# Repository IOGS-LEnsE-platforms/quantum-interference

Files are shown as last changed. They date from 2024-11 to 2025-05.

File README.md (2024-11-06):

# quantum-interference

*LEnsE / Institut d'Optique / Dephi Project / 2025*

## References

P. Grangier, G. Roger, and A. Aspect, “Experimental Evidence for a Photon Anticorrelation Effect on a Beam Splitter: A New Light on SinglePhoton Interferences”, Europys. Lett. 1 (1986), 173-179, abbreviated GRA
in the text.

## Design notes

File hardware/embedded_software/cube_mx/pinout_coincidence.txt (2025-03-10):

Period
======

FCLK = 170 MHz
ARR = 2^16
PSC = 2615

Tout = (ARR + 1)(PSC + 1) / FCLK

Pinout
======

PB_4 -> Out : TIM16 pulse

Interrupts EXTI
---------------
PA_1 - A
PA_4 - B
PA_6 - C
PA_8 - AB
PB_5 - AC
PA_12 - BC
PA_9 - ABC

Others inputs/outputs
---------------------
PA_2 - Analog Potentiometer 
PB_7 - SW1 input
PB_0 - LED1 output

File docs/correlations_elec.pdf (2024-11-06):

## Chapter 6: Coincidence Detection Electronics

Experiments in quantum optics utilizing entangled photons rely on the coincident detection of two or more photons. Some experiments of this type use combinations of time-to-amplitude converters (TAC) and single-channel analyzers (SCA) to detect coincident signals from the photodetectors[5, 6, 10]. The TAC/SCA combinations cost several thousand dollars. This chapter describes a fast logic circuit which fulfils the coincidence counting requirements and can be built for under 40. The circuit is designed to receive 25ns TTL signals and detect coincidences in a 25ns window. The output signals are designed to be 250ns TTL pulses. The coincidence window is not adjustable, but a similar circuit with a different coincidence window is easy to design. Additionally, the design of this circuit can be extended to detect pairs of coincidences between more than two inputs.
A circuit was built according to this design and tests showed it had a coincidence window of between 18ns and 30ns. The output signals where clear and should be easy to count, with a digital counting card for example. The following sections document the design, construction, and performance of the coincidence circuit.

### 6.1 Design

The design for this circuit was published in 2002 by Dehlinger and Mitchell[7]. The only changes from their design to the one described here are two capacitors added for power stability[41]. A schematic is shown in Fig. 6.1(a). The circuit consists of two 74ACT74 dual D-type positive edge-triggered flip-flops, or 4 flip-flops total. Input pulses terminate into a 50Ω load as required by the photodetectors.
Chips 1 and 4 simply relay a pulse received on K to Q. The duration of the pulse from Q depends on the time constant of the RC combination between Q and S, which for the resistor and capacitor chosen is 1kΩ · 220pF = 220ns. This pulse duration should be easy to count with a computer data acquisition card.
Chip 3 in the circuit delays the signal at Bin for the time needed to clock and reset, typically 13ns, with a minimum of 6.5ns and maximum of 19.5ns[42]. In the case of coincident input, the signal from Ain sets D on chip 2 to HIGH before the rising pulse from the delayed Bin triggers the circuit. From the truth table (Table 6.1) it is clear that this combination will issue HIGH on Q, the coincidence output. The RC reset on chip 2 determines the length of the coincidence signal as in chips 1 and 4. Coincidence detection can only occur while Ain is HIGH, so the coincidence window for the 25ns input pulses is 25ns.

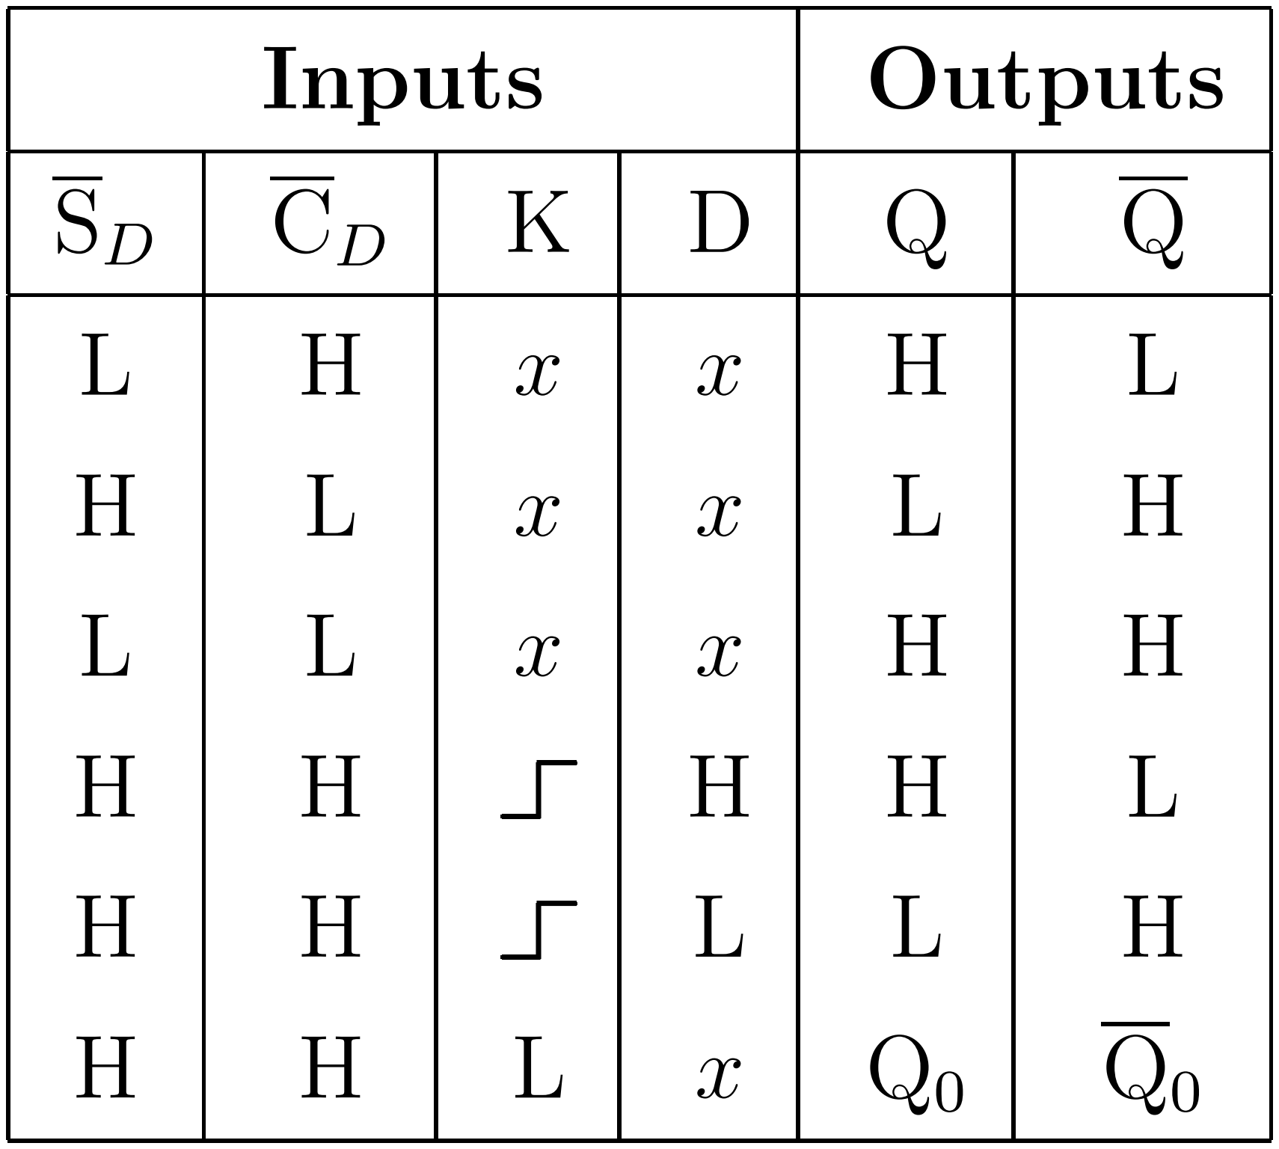
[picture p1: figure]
Inputs; Outputs

Table 6.1: The truth table for each half of a 74ACT74 logic chip. H, L, , and x correspond to TTL HIGH, LOW, rising, and immaterial voltages, respectively[42].

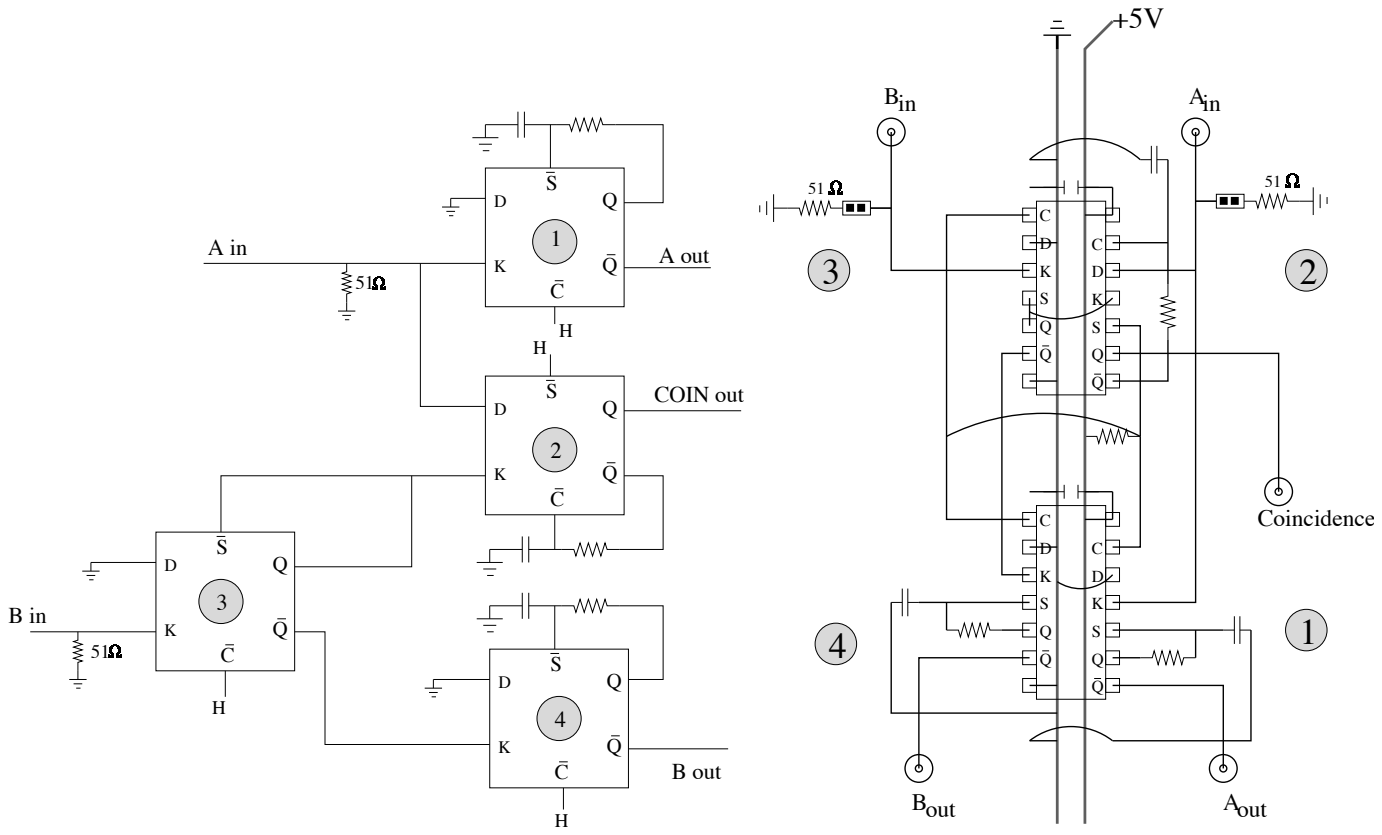
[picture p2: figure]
B out; A out; COIN out; Bin; Ain; Bout; Aout; Coincidence

(a) A schematic diagram of the coincidence detection circuit. Each square is half a 74ACT74 logic chip. H indicates TTL high, +5V .
(b) Diagram of the circuit layout as constructed, including jumpers and additional capacitors across the bus.

Figure 6.1: Two schematic diagrams of the coincidence detection circuit. All capacitors are 220pF except the two across the bus. All resistors are 1kΩ except the two labeled 51Ω.

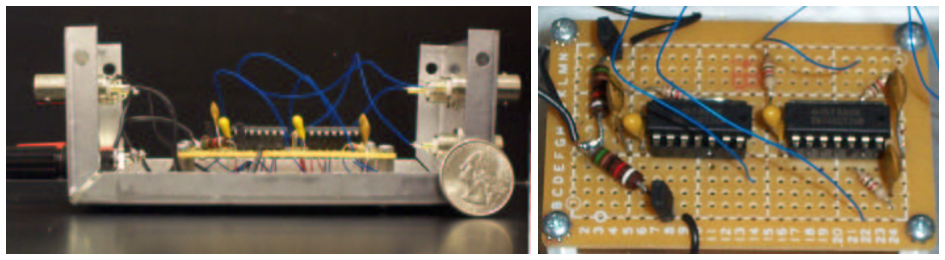
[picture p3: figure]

(a) Side view. | (b) Close up.

Figure 6.2: Pictures of the coincidence circuit.

### 6.2 Construction

The layout of the circuit is shown in Fig. 6.1(b) as assembled on a perforated circuit board with components on top and solder and wiring underneath. Each hole of the board is surrounded by a copper pad to which solder adheres easily. All components are listed in Table 6.2.
The central bus provides stable power and ground to the whole circuit. It was made by soldering two segments of 22 gauge wire to each pad in adjacent rows. By only stripping the portion of the wire to be soldered the wire on the top side remained covered.
The two 14 pin sockets were placed to straddle the bus, and were soldered at each pad. The sockets allow for easy replacement of the logic chips, should it be necessary. A 22µF capacitor was placed across the bus next to the power pin of each chip to increase power stability. A 1kΩ was placed between the bus and the connection point for TTL HIGH for chip protection.
Twenty-two gauge wire was chosen for Ain and Bin, but that choice was unimportant. All remaining wires are 30 gauge because the interconnection soldering is tight and would be difficult to manage with large wire. The wires for the output signals were threaded back up through the board so that any strain is put on the sheathed portion of the wire instead of the connections.
The 51Ω terminations on the inputs are the necessary load required by the photodetectors, but are inhibitory during testing of the circuit. They were joined to the inputs through jumpers so that the terminations can be disconnected by removing the jumper caps.
The completed circuit is mounted inside a metal box to provide electromagnetic shielding and mounts for BNC and banana jacks. The input and output signals travel on BNC cables and the power comes through banana jacks. The connecter holes were drilled with a drill press and drill bit sizes 25

64 and 5
16 for the BNC and
banana jacks, respectively. It was easy to solder wires into the BNC jacks. However, solder did not bond well to the banana jack posts or to the box. In order to avoid the

Item | Qt. | /item
51Ω resistor | 2 | < 1
1kΩ resistor | 4 | < 1
220pF capacitor | 3 | < 1
22µF @16V dc capacitor | 2 | < 1
14-pin socket | 2 | < 1
74ACT74 logic chip | 2 | < 1
Jumper pins | 2 | < 1
Project box | 1 | 3
Perforated circuit board | 1 | 2
Banana jack panel mount | 2 | 1
BNC panel mount | 5 | 1
22 gauge solid wire
30 gauge solid wire
Total < 40

Table 6.2: Materials used to build the coincidence circuit.

need to solder the bus ground to both a banana post and the box, it would be better to use a special grounding banana jack. Fig. 6.2 shows pictures of the completed circuit.
The following are useful notes for anyone attempting to create a similar circuit.

It is difficult to strip 30 gauge wire without a wire stripper.

The stripped portions of any gauge wire are much weaker than the protected portions. The sheath should be kept wherever possible and stripped portions should be bent as little as possible to avoid breaking.

The 30 gauge wire is easier to solder and more robust if it is inserted into the perf board hole than if it is laid sideways on the board.

Some of the connections between pins of the socket and the bus can be made without wire, just by connecting the blobs of solder.

Although some of the components in this circuit were not trimmed short enough to rest on the board, such trimming is a good idea in general since it prevents possible undue strain on the copper pads underneath.

A special grounding banana jack (instead of insulated) is recommended for the ground connection, to remove the need to solder to both the banana post and the box.

### 6.3 Performance

The circuit was tested with a HP 8111A 20MHz function generator and an oscilloscope. The function generator can supply a signal which mimics the 25ns TTL signal from a photodetector we expect as input. The function generator is built for 50Ω signal termination. The oscilloscope was able to display the signals on the circuit inputs and outputs, but ringing made it necessary to use a scope probe, with its shielding connected to the circuit’s ground.
When the signal from the function generator was connected to Ain, Aout showed a 250ns pulse, while Bout and Coinout remained flat. Connecting the signal to Bin produced a 250ns pulse at Bout, while Aout and Coinout remained flat. When the function generator signal was connected to Ain and Bin at the same time it was necessary to disconnect a 50Ω termination by removing a jumper, so that the 50Ω load on the function generated was maintained. In this situation, with signal input at both Ain and Bin, all three outputs showed 250ns pulses.
To make sure that sufficiently separated signals on Ain and Bin are resolved as not coincident, part of the signal from the function generator was subjected to the propagation delay of a 7408 2-input positive AND gate. The propagation delay for that chip is typically 9ns according to the datasheet. When one input received the signal from the function generator and the other input received the signal delayed through 2 AND gates, there was no coincidence detected. However a delay of 1 AND gate was not enough to prevent coincidence detection. This is direct evidence that the circuit has a coincidence window of between 18ns (signal 9ns away on either side are coincident) and 36ns (signal 18ns away on either side are not). This fits our expectation that the window is 25ns, the length of the signal at Ain.

### 6.4 Summary

The circuit described in this chapter detects coincidences for 25ns 50Ω terminated TTL pulses with a coincidence window of 18ns to 36ns. This is ideal for quantum optics experiments which rely on coincident detection of photons using photodetectors such as the SPCM from Perkin-Elmer. The circuit can be constructed easily and for less than 40, and can be tested using a function generator and oscilloscope. As an end note, this circuit can be easily extended to accommodate three or more input signals, as shown in Fig. 6.3. Quantum optics experiments with a gating detector and two signal detectors are common and would use this extended circuit.

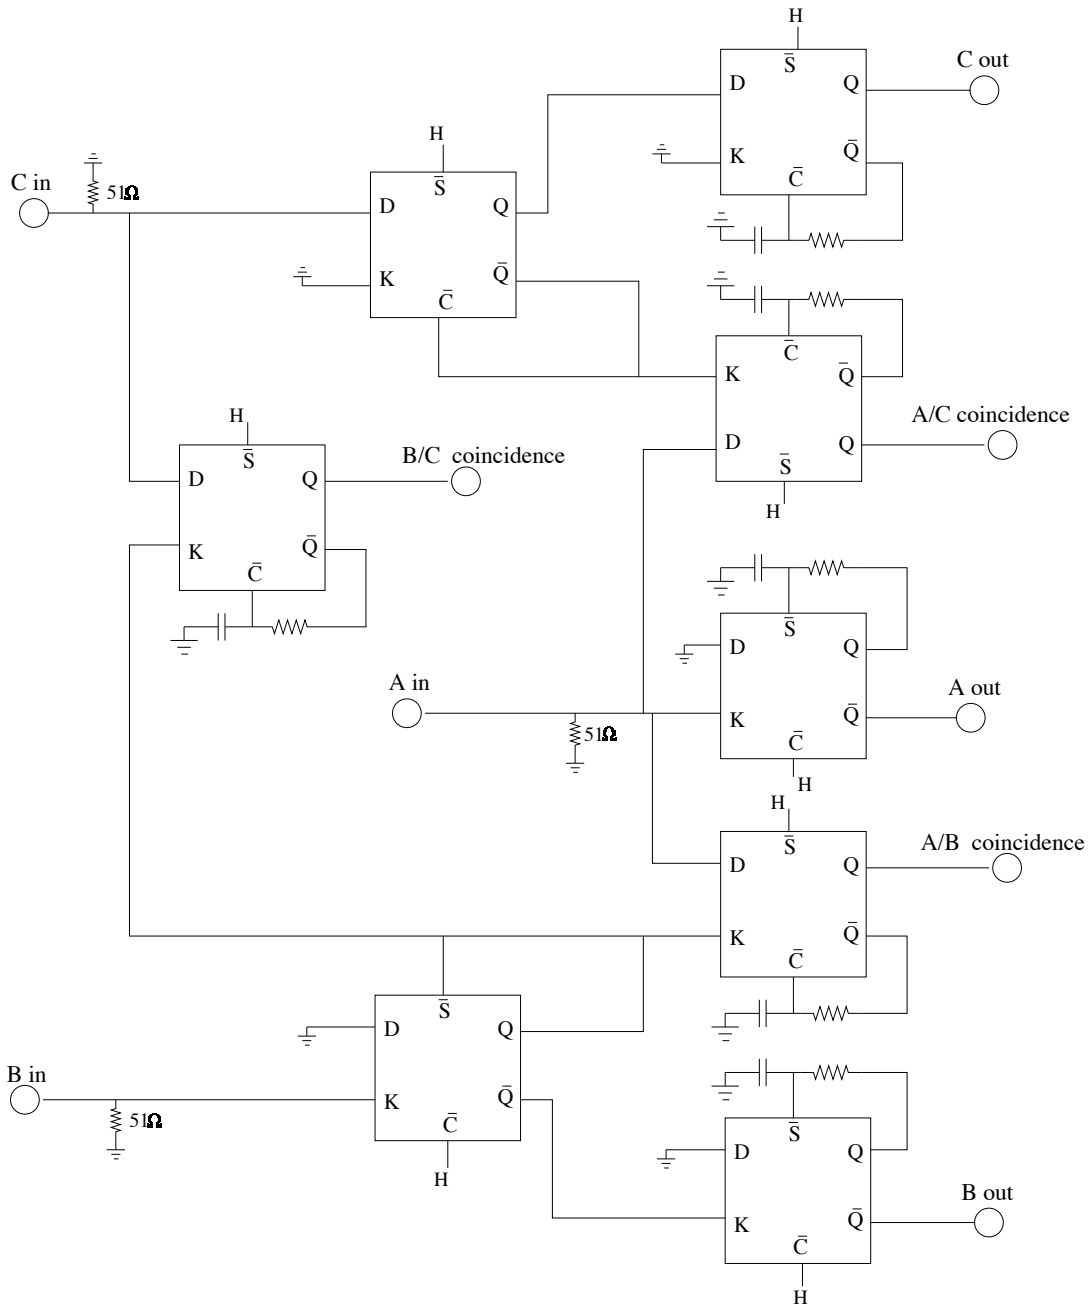
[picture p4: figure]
B/C coincidence; A/B coincidence; B out; A out; A/C coincidence; C out

Figure 6.3: The coincidence circuit extended to detect coincidences between pairs of any three inputs.

### References

[1] A. Einstein, B. Podolsky, and N. Rosen. Can quantum-mechanical description of physical reality be considered complete? Phys. Rev., 47:777–780, 1935.
[2] John S. Bell. On the einstein podalsky rosen paradox. Physics, 1(3):195–200, 1964. This article reprinted in [19].
[3] A. Aspect, P. Grangier, and G. Roger. Experimental tests of realistic local theories via bell’s theorem. Phys. Rev. Lett., 1981.
[4] A. Aspect, P. Grangier, and G. Roger. Experimental realization of einsteinpodalsky-rosen-bohm gedankenexperiment: A new violation of bell’s inequalities. Phys. Rev. Lett., 49:91, 1982.
[5] Paul G. Kwiat, Klaus Mattle, Harald Weinfurter, and Anlon Zeilinger. New high-intensity source of polarization-entangled photon pairs. Physical Review Letters, 75(24):4337–4342, December 1995.
[6] Paul G. Kwiat, Edo Waks, Andrew G. White, Ian Appelbaum, and Philipe H. Eberhard. Ultrabright source of polarization-entangled photons. Physical Review A, 60(2):R773–R776, August 1999.
[7] D. Dehlinger and M. W Mitchell. Entangled photon apparatus for the undergraduate laboratory. Am. J. Phys., 70:898–902, 2002.
[8] D. Dehlinger and M. W Mitchell. Entangled photons, nonlocality, and bell inequalities in the undergraduate laboratory. Am. J. Phys., 70(9):903–910, September 2002.
[9] C. H. Holbrow, E. Galvez, and M. E. Parks. Photon quantum mechanics and beam splitters. Am. J. Phys., 70(3):260–265, March 2002.
[10] J. J. Thorn, M. S. Neel, V. W. Donato, G. S. Bergreen, R. E. Davies, and
M. Beck. Observing the quantum behavior of light in an undergraduate laboratory. Am. J. Phys., 2004. Preprint.
[11] A. K. Ekert. Quantum cryptography based on bell’s theorem. Phys. Rev. Lett., 67:661–663, 1991.
[12] C. H. Bennett. Quantum cryptography using any two nonorthogonal states. Phys. Rev. Lett., 1992.

[13] Gilles | Brassard. | A | bibliography | of | quantum | cryptography.
http://www.cs.mcgill.ca/ crepeau/CRYPTO/Biblio-QC.html, 1998.
[14] Michael A. Neilsen and Isaac L. Chuang. Quantum computation and quantum information. Cambridge U. Press, 2000.
[15] Peter W. Shor. Polynomial-time algorithms for prime factorization and discrete logarithms on a quantum computer. SIAM J. Comput., 26(5):1484–1509, 1997.
[16] David J. Griffiths. Introduction to Quantum Mechanics. Prentice Hall, NJ, 1995.
[17] N David Mermin. Is the moon there when nobody looks? reality and the quantum theory. Physics Today, April 1985.
[18] David Bohm. Quantum Theory. Prentice-Hall, Englewood Cliffs, NJ, 1951. pp. 614-619.
[19] M. Bell, K. Gottfried, and M. Veltman, editors. John S. Bell on The Foundations of Quantun Mechanics. World Scientific, NJ, 2001.
[20] J.F. Clauser, M.A. Horne, A. Shimony, and R.A. Holt. Proposed experiment to test local hidden-variable theories. Phys. Rev. Lett., 23(15):880–884, 1969.
[21] Paul G. Kwiat, Philippe H. Eberhard, Aephraim M. Steinberg, and Raymond Y. Chiao. Proposal for a loophole-free bell inequality experiment. Phys. Rev. A, 49(5):3209–3221, May 1994.
[22] P. H. Eberhard. Phys. Rev. A, 1993.
[23] P. Grangier, G. Roger, and A. Aspect. Experimental evidence for a photon anticorrelation effect on a beam splitter: A new light on single-photon interferences. Europhys. Lett., 1986.
[24] Robert W. Boyd. Nonlinear Optics. Academic Press, second edition, 2003.
[25] Xinping Zhang. High-repitition-rate Femtosecond Optical Parametric Oscillators Based on KTP and PPLN. PhD thesis, Philipps-Universit¨at Marburg, Marburg, Germany, 2002. Chapter 2.
[26] Cleveland Crystals Inc. BBO and LBO. http://www.clevelandcrystals.com/BBOLBO.shtml.
[27] Almaz Optics Inc. BBO crystal. http://www.almazoptics.com/Bbo.htm.
[28] SDLN Coretech Crystal Co. Beta barium borate. http://www.coretech.com.cn/BBO.HTM.

[29] Paul G. Kwiat. J. Mod. Opt., 44:2173, 1997.
[30] R. Y. Chiao, P. G. Kwiat, and A. M. Steinberg. Optical tests of quantum mechanics. In Advances in Atomic, Molecular, and Optical Physics, volume 34, pages 35–83. Academic, 1994.
[31] Photon quantum mechanics. Internet. http://departments.colgate.edu/physics/research/Photon/photon_quantum_m%echanics.htm.
[32] M.K. Beck. Modern quantum mechanics experiments for undergraduates. Internet, 2004. http://marcus.whitman.edu/~beckmk/QM/.
[33] Edmund Optics. Solid state lasers. http://www.edmundoptics.com/, April 2004.
[34] Eugene Hecht. Optics. Pearson Addison Wesley, 4th edition, 2001.
[35] Casix Inc. Waveplates. http://casix.com/product/Waveplate.htm.
[36] Perkin-Elmer Optoelectronics. Single photon counting module, SPCM-AQR series. Internet. Datasheet.
[37] Perkin-Elmer Optoelectronics. SPCM-AQ4C, single photon counting array. Internet. Datasheet.
[38] Perkin-Elmer Optoelectronics. SPCM AQ4C Four Channel Photon Counting Module–User Guide, May 2003.
[39] D.W. Finn and M. J. Ouellette. Compact fluorescent lamps: What you should know. Progressive Architecture, pages 89–92, August 1992.
[40] John R. Taylor. Introduction to Error Analysis. University Science Books, CA, second edition, 1997.
[41] William Mohler. Personal Communication, 2003. Oberlin College.
[42] Semiconductor Components Industries, LLC. 74ACT74 Datasheet, May 2001. <http://onsemi.com>.

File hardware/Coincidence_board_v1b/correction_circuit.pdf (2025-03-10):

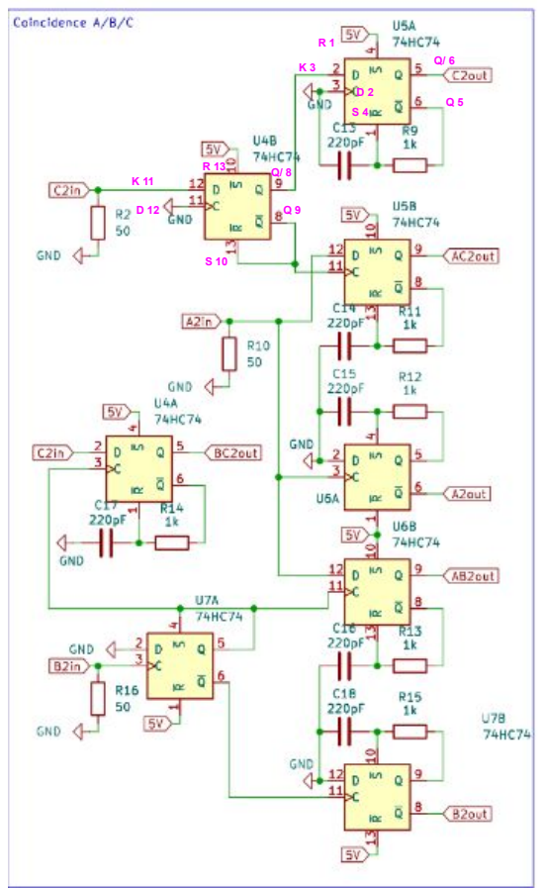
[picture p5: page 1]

R 13 | Q/ 8

Q 9

S 10

K 11

D 12

Q/ 6

Q 5
S 4

D 2

K 3

R 1

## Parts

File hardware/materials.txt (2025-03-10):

Coincidence Board v2
====================
	Developed by LEnsE / 2025

Board with Nucleo G431KB 
D-Flip 74HC74 PDIP circuits

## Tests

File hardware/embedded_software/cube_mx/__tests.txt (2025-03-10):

Test on Nucleo G431KB

// Embedded program //
======================

+ 10/03/2025 - JV - Test coincidence_v1 program (HAL and CubeIDE)
-----------------------------------------------------------------
- Test with 7 inputs (interrupt EXTI) :
	+ pulses of 250 ns, amplitude 0-3V
- Results
	+ A/B/C -> 600 kHz
	+ AB/BC/AC/ABC -> 50 kHz

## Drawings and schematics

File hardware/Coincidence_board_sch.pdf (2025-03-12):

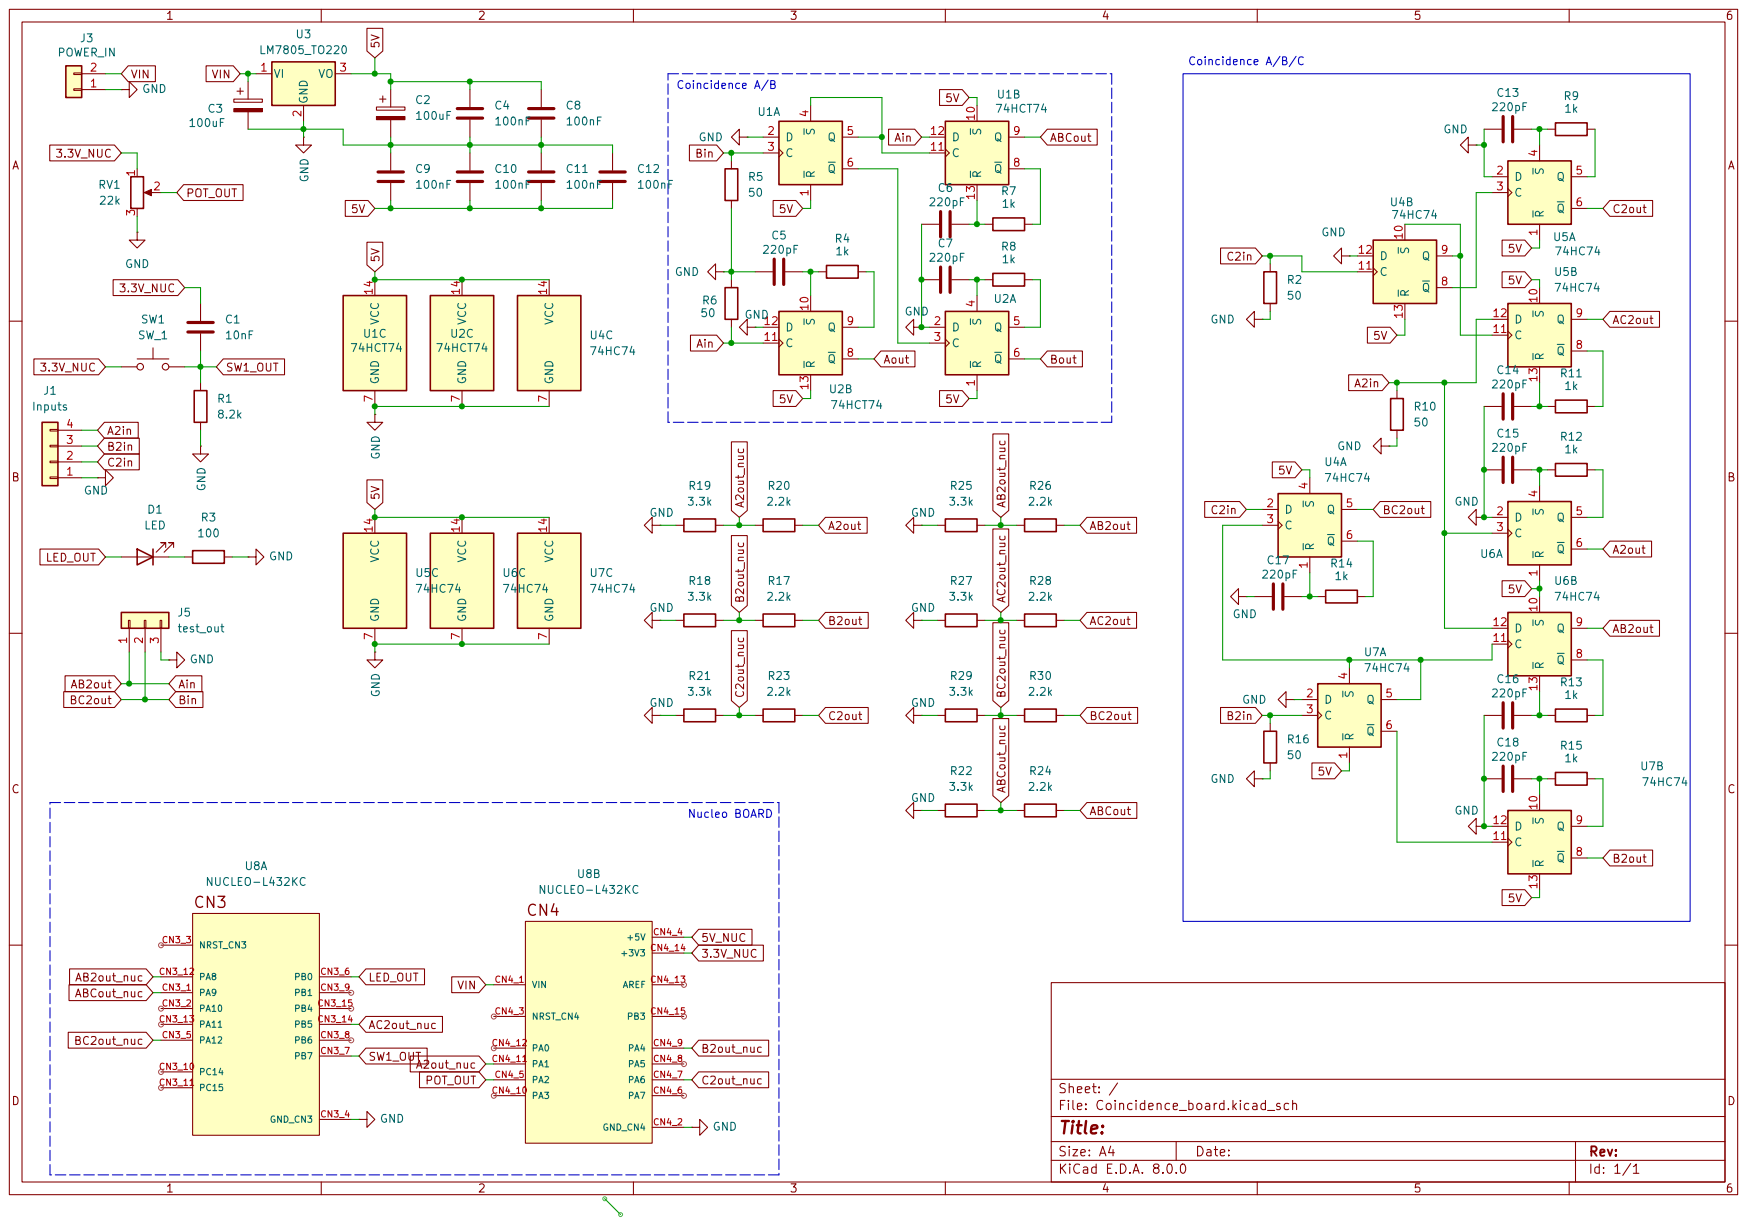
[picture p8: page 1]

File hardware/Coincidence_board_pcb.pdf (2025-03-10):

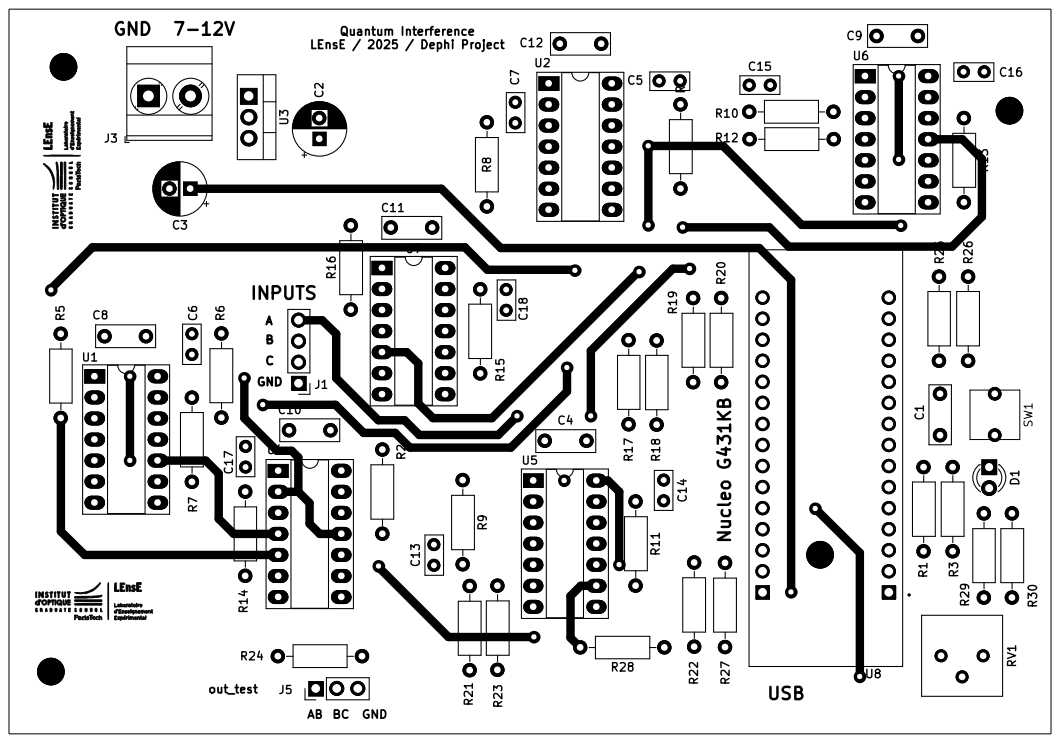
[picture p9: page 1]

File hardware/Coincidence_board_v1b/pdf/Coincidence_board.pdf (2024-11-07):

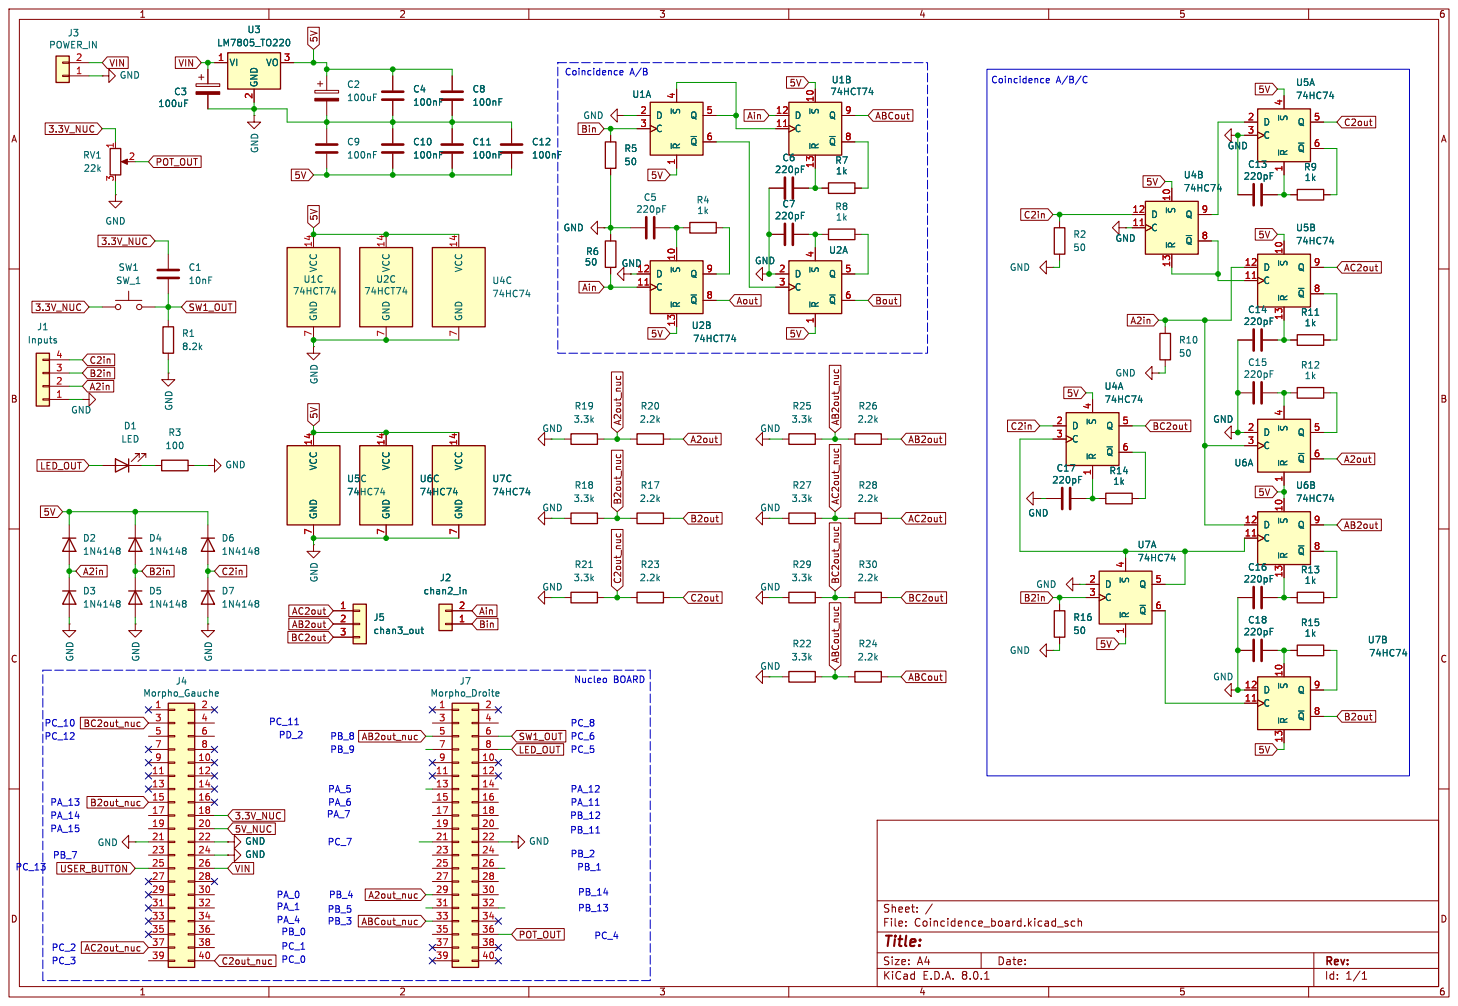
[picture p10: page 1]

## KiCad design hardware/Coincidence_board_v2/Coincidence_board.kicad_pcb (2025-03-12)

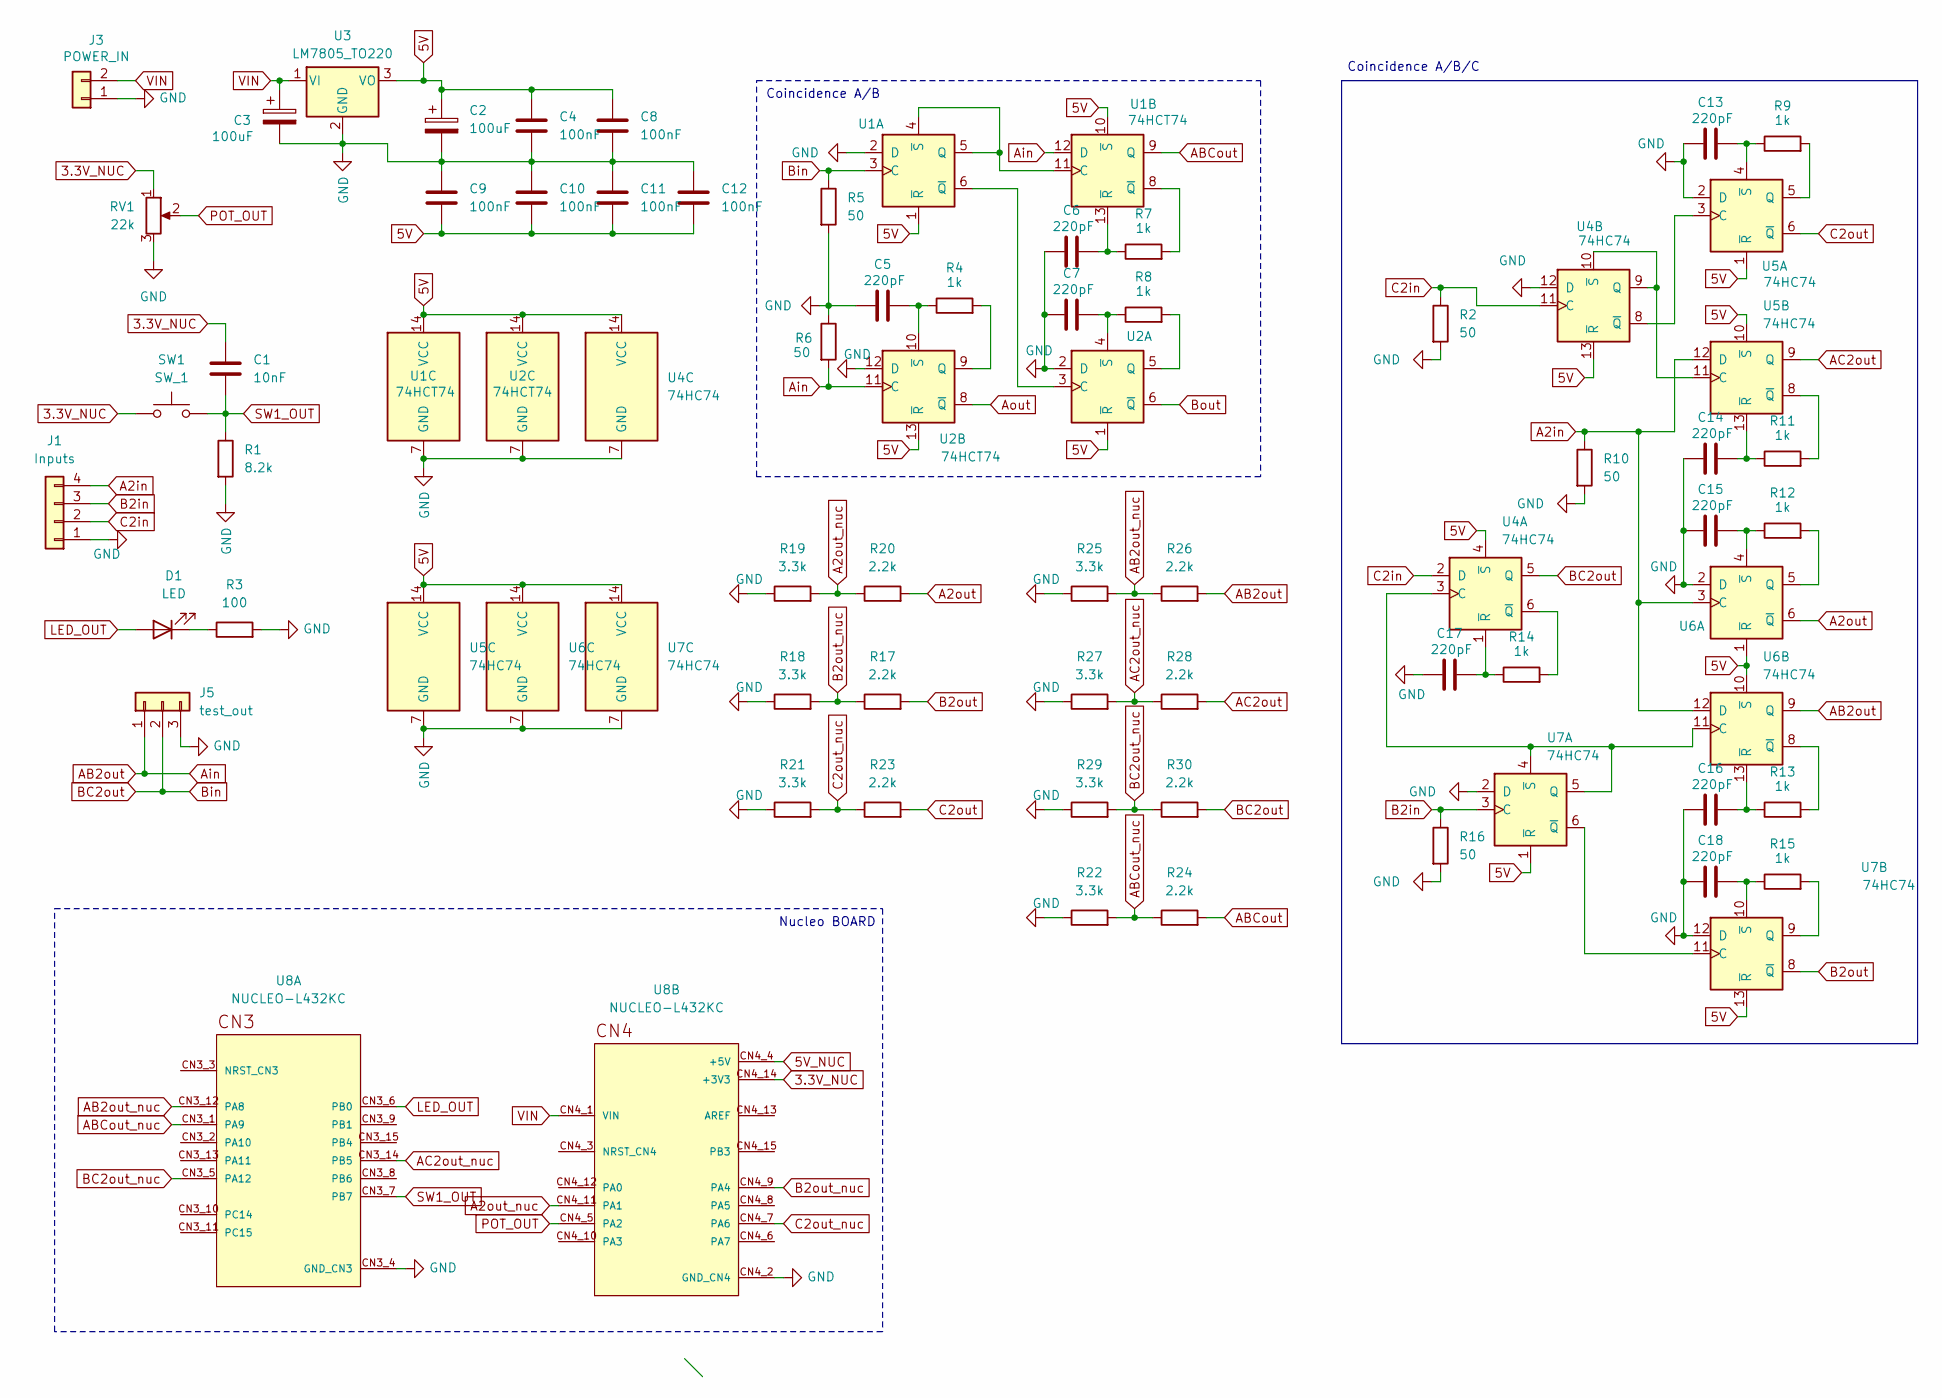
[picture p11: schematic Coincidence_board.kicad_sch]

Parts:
C1: 10nF; C_Rect_L7.0mm_W2.5mm_P5.00mm
C2, C3: 100uF; CP_Radial_D6.3mm_P2.50mm
C4, C8, C9, C10, C11, C12: 100nF; C_Rect_L7.0mm_W2.5mm_P5.00mm
C5, C6, C7, C13, C14, C15, C16, C17, C18: 220pF; C_Rect_L4.6mm_W2.0mm_P2.50mm_MKS02_FKP02
D1: LED; LED_D3.0mm_Clear
J1: Inputs; PinHeader_1x04_P2.54mm_Vertical
J3: POWER_IN; TerminalBlock_Phoenix_MKDS-3-2-5.08_1x02_P5.08mm_Horizontal
J5: test_out; PinHeader_1x03_P2.54mm_Vertical
R1: 8.2k; R_Axial_DIN0207_L6.3mm_D2.5mm_P10.16mm_Horizontal
R2, R5, R6, R10, R16: 50; R_Axial_DIN0207_L6.3mm_D2.5mm_P10.16mm_Horizontal
R3: 100; R_Axial_DIN0207_L6.3mm_D2.5mm_P10.16mm_Horizontal
R4, R7, R8, R9, R11, R12, R13, R14, R15: 1k; R_Axial_DIN0207_L6.3mm_D2.5mm_P10.16mm_Horizontal
R17, R20, R23, R24, R26, R28, R30: 2.2k; R_Axial_DIN0207_L6.3mm_D2.5mm_P10.16mm_Horizontal
R18, R19, R21, R22, R25, R27, R29: 3.3k; R_Axial_DIN0207_L6.3mm_D2.5mm_P10.16mm_Horizontal
RV1: 22k; Potentiometer_Bourns_3386P_Vertical
SW1: SW_1; Switch
U1, U2: 74HCT74; DIP-14_W7.62mm_Socket_LongPads
U3: LM7805_TO220; TO-220-3_Vertical
U4, U5, U6, U7: 74HC74; DIP-14_W7.62mm_Socket_LongPads
U8: NUCLEO-L432KC; MODULE_NUCLEO-L432KC; PARTREV N/A

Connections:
3.3V_NUC: C1.1, RV1.1, SW1.1, U8.CN4_14 (+3V3)
5V: C2.1, C4.1, C8.1, C9.2, C10.2, C11.2, C12.2, U1.1 (~R), U1.10 (~S), U1.14 (VCC), U2.1 (~R), U2.13 (~R), U2.14 (VCC), U3.3 (VO), U4.4 (~S), U4.13 (~R), U4.14 (VCC), U5.1 (~R), U5.10 (~S), U5.14 (VCC), U6.1 (~R), U6.10 (~S), U6.14 (VCC), U7.1 (~R), U7.13 (~R), U7.14 (VCC)
5V_NUC: U8.CN4_4 (+5V)
A2in: J1.4, R10.1, U5.12 (D), U6.3 (C), U6.12 (D)
A2out: R20.2, U6.6 (~Q)
A2out_nuc: R19.2, R20.1, U8.CN4_11 (PA1)
AB2out: J5.1, R6.2, R26.2, U1.12 (D), U2.11 (C), U6.9 (Q)
AB2out_nuc: R25.2, R26.1, U8.CN3_12 (PA8)
ABCout: R24.2, U1.9 (Q)
ABCout_nuc: R22.2, R24.1, U8.CN3_1 (PA9)
AC2out: R28.2, U5.9 (Q)
AC2out_nuc: R27.2, R28.1, U8.CN3_14 (PB5)
Aout: U2.8 (~Q)
B2in: J1.3, R16.1, U7.3 (C)
B2out: R17.2, U7.8 (~Q)
B2out_nuc: R17.1, R18.2, U8.CN4_9 (PA4)
BC2out: J5.2, R5.1, R30.2, U1.3 (C), U4.5 (Q)
BC2out_nuc: R29.2, R30.1, U8.CN3_5 (PA12)
Bout: U2.6 (~Q)
C2in: J1.2, R2.1, U4.2 (D), U4.11 (C)
C2out: R23.2, U5.6 (~Q)
C2out_nuc: R21.2, R23.1, U8.CN4_7 (PA6)
GND: C2.2, C3.2, C4.2, C5.1, C6.1, C7.1, C8.2, C9.1, C10.1, C11.1, C12.1, C13.1, C14.1, C15.1, C16.1, C17.1, C18.1, J1.1, J3.1, J5.3, R1.2, R2.2, R3.2, R5.2, R6.1, R10.2, R16.2, R18.1, R19.1, R21.1, R22.1, R25.1, R27.1, R29.1, RV1.3, U1.2 (D), U1.7 (GND), U2.2 (D), U2.7 (GND), U2.12 (D), U3.2 (GND), U4.7 (GND), U4.12 (D), U5.2 (D), U5.7 (GND), U6.2 (D), U6.7 (GND), U7.2 (D), U7.7 (GND), U7.12 (D), U8.CN3_4 (GND_CN3), U8.CN4_2 (GND_CN4)
LED_OUT: D1.2 (A), U8.CN3_6 (PB0)
unnamed: D1.1 (K), R3.1
unnamed: U1.4 (~S), U1.5 (Q), U1.11 (C)
unnamed: U1.6 (~Q), U2.3 (C)
unnamed: R7.2, U1.8 (~Q)
unnamed: C6.2, R7.1, U1.13 (~R)
unnamed: R8.2, U2.5 (Q)
unnamed: C7.2, R8.1, U2.4 (~S)
unnamed: R4.2, U2.9 (Q)
unnamed: C5.2, R4.1, U2.10 (~S)
unnamed: U4.3 (C), U6.11 (C), U7.4 (~S), U7.5 (Q)
unnamed: R14.2, U4.6 (~Q)
unnamed: C17.2, R14.1, U4.1 (~R)
unnamed: U4.9 (Q), U4.10 (~S), U5.11 (C)
unnamed: U4.8 (~Q), U5.3 (C)
unnamed: R9.2, U5.5 (Q)
unnamed: C13.2, R9.1, U5.4 (~S)
unnamed: R11.2, U5.8 (~Q)
unnamed: C14.2, R11.1, U5.13 (~R)
unnamed: R12.2, U6.5 (Q)
unnamed: C15.2, R12.1, U6.4 (~S)
unnamed: R13.2, U6.8 (~Q)
unnamed: C16.2, R13.1, U6.13 (~R)
unnamed: U7.6 (~Q), U7.11 (C)
unnamed: R15.2, U7.9 (Q)
unnamed: C18.2, R15.1, U7.10 (~S)
POT_OUT: RV1.2, U8.CN4_5 (PA2)
SW1_OUT: C1.2, R1.1, SW1.2, U8.CN3_7 (PB7)
VIN: C3.1, J3.2, U3.1 (VI), U8.CN4_1 (VIN)

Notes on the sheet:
Coincidence A/B
Coincidence A/B/C
Nucleo BOARD

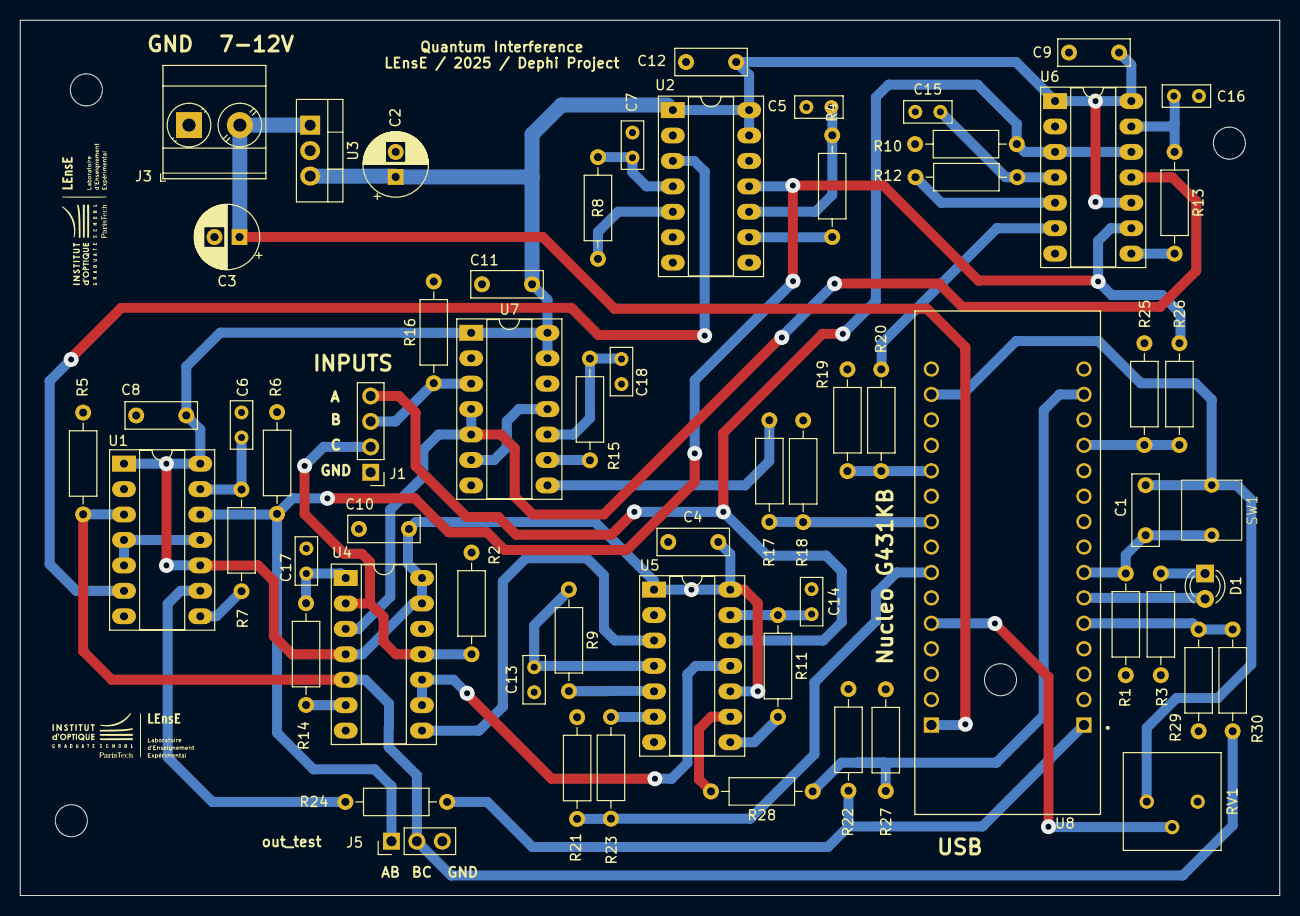
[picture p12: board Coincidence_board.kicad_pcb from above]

Board: 2 copper layers, 125.8 x 87.4 mm, 64 parts (0 on the bottom side), 49 nets.

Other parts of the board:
M: MountingHole_3.2mm_M3
M#2: MountingHole_3.2mm_M3

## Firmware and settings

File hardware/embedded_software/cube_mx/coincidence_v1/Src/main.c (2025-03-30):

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
/* Includes ------------------------------------------------------------------*/
#include "main.h"
#include "lptim.h"
#include "tim.h"
#include "usart.h"
#include "gpio.h"

/* USER CODE BEGIN Includes */
#include <stdbool.h>
#include <stdio.h>
#include <string.h>

/* USER CODE END Includes */


/* USER CODE BEGIN PV */
char 		txBuffer[20] = {0};
int			a_counter = 0, a_counter_save = 0;
int			b_counter = 0, b_counter_save = 0;
int			c_counter = 0, c_counter_save = 0;
int			ab_counter = 0, ab_counter_save = 0;
int			ac_counter = 0, ac_counter_save = 0;
int			bc_counter = 0, bc_counter_save = 0;
int			abc_counter = 0, abc_counter_save = 0;

/*Configure GPIO pins : PA4 PA5 PA6 PA7
                         PA8 PA9 PA10 PA11 */


/* USER CODE END PV */

void SystemClock_Config(void);
/**
  * @brief  The application entry point.
  * @retval int
  */
int main(void)
{

  /* MCU Configuration--------------------------------------------------------*/

  /* Reset of all peripherals, Initializes the Flash interface and the Systick. */
  HAL_Init();

  /* Configure the system clock */
  SystemClock_Config();

  /* Initialize all configured peripherals */
  MX_GPIO_Init();
  MX_USART2_UART_Init();
  MX_LPTIM1_Init();
  MX_TIM16_Init();
  /* USER CODE BEGIN 2 */
  // TIM16 - 16 bits Timer / Period = (PSC+1)(ARR+1) / 170MHz  (??)  ARR = 2^16
  // For PSC = 2615 -> T = 1000ms

  // Init
  txBuffer[0] = 'Z';
  txBuffer[1] = '\r';
  txBuffer[2] = '\n';
  txBuffer[3] = '\0';


  // Start TIM16 timer
  HAL_TIM_Base_Start_IT(&htim16);
  /* USER CODE END 2 */

  /* Infinite loop */
  /* USER CODE BEGIN WHILE */
  while (1)
  {
	//HAL_UART_Transmit(&huart2, txBuffer, 4, 1000);
	//HAL_Delay(100);

    /* USER CODE END WHILE */

    /* USER CODE BEGIN 3 */
  }
  /* USER CODE END 3 */
}

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
/* USER CODE BEGIN 4 */
// Interrupt on EXTI - PA4, PA5...
void HAL_GPIO_EXTI_Callback(uint16_t GPIO_Pin)
{
    if(GPIO_Pin == GPIO_PIN_1) // If The INT Source Is EXTI Line1 (A1 Pin)
    {
    	a_counter++;
    }
    if(GPIO_Pin == GPIO_PIN_4) // If The INT Source Is EXTI Line4 (A4 Pin)
    {
    	b_counter++;
    }
    if(GPIO_Pin == GPIO_PIN_6) // If The INT Source Is EXTI Line6 (A6 Pin)
    {
    	c_counter++;
    }
    if(GPIO_Pin == GPIO_PIN_8) // If The INT Source Is EXTI Line8 (A8 Pin)
    {
    	ab_counter++;
    }
    if(GPIO_Pin == GPIO_PIN_9) // If The INT Source Is EXTI Line9 (A9 Pin)
    {
    	abc_counter++;
    }
    if(GPIO_Pin == GPIO_PIN_12) // If The INT Source Is EXTI Line12 (A12 Pin)
    {
    	bc_counter++;
    }
    if(GPIO_Pin == GPIO_PIN_5) // If The INT Source Is EXTI Line5 (PB5 Pin)
    {
    	ac_counter++;
    }
}

// Interrupt on TIM - TIM16
void HAL_TIM_PeriodElapsedCallback(TIM_HandleTypeDef* htim)
{
    HAL_GPIO_WritePin(GPIOB, GPIO_PIN_4, GPIO_PIN_SET);
    a_counter_save = a_counter;
    a_counter = 0;
    b_counter_save = b_counter;
    b_counter = 0;
    c_counter_save = c_counter;
    c_counter = 0;
    ab_counter_save = ab_counter;
    ab_counter = 0;
    ac_counter_save = ac_counter;
    ac_counter = 0;
    bc_counter_save = bc_counter;
    bc_counter = 0;
    abc_counter_save = abc_counter;
    abc_counter = 0;
	sprintf(txBuffer, "A=%d\n", a_counter_save+1);
    HAL_UART_Transmit(&huart2, (uint8_t *)txBuffer, strlen(txBuffer), 1000);
	sprintf(txBuffer, "B=%d\n", b_counter_save+1);
    HAL_UART_Transmit(&huart2, (uint8_t *)txBuffer, strlen(txBuffer), 1000);
	sprintf(txBuffer, "C=%d\n", c_counter_save+1);
    HAL_UART_Transmit(&huart2, (uint8_t *)txBuffer, strlen(txBuffer), 1000);
	sprintf(txBuffer, "AB=%d\n", ab_counter_save+1);
    HAL_UART_Transmit(&huart2, (uint8_t *)txBuffer, strlen(txBuffer), 1000);
	sprintf(txBuffer, "AC=%d\n", ac_counter_save+1);
    HAL_UART_Transmit(&huart2, (uint8_t *)txBuffer, strlen(txBuffer), 1000);
	sprintf(txBuffer, "BC=%d\n", bc_counter_save+1);
    HAL_UART_Transmit(&huart2, (uint8_t *)txBuffer, strlen(txBuffer), 1000);
	sprintf(txBuffer, "ABC=%d\n", abc_counter_save+1);
    HAL_UART_Transmit(&huart2, (uint8_t *)txBuffer, strlen(txBuffer), 1000);
    HAL_GPIO_WritePin(GPIOB, GPIO_PIN_4, GPIO_PIN_RESET);
}
/* USER CODE END 4 */
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


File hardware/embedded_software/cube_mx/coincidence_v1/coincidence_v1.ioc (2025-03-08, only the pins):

Mcu.UserName=STM32G431KBTx
PA1.Signal=GPXTI1
PA12.Signal=GPXTI12
PA13.GPIO_Label=T_SWDIO
PA13.Signal=SYS_JTMS-SWDIO
PA14.GPIO_Label=T_SWCLK
PA14.Signal=SYS_JTCK-SWCLK
PA2.GPIO_Label=USART2_TX [ST-LINKV3E_VCP_RX]
PA2.Signal=USART2_TX
PA3.GPIO_Label=USART2_RX [ST-LINKV3E_VCP_TX]
PA3.Signal=USART2_RX
PA4.Signal=GPXTI4
PA6.Signal=GPXTI6
PA8.Signal=GPXTI8
PA9.Signal=GPXTI9
PB3.GPIO_Label=T_SWO
PB3.Signal=SYS_JTDO-SWO
PB4.Signal=GPIO_Output
PB5.Signal=GPXTI5
PB8-BOOT0.GPIO_Label=LD2 [green]
PB8-BOOT0.Signal=GPIO_Output

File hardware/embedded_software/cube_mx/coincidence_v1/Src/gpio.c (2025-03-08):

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

/* Includes ------------------------------------------------------------------*/
#include "gpio.h"

/*----------------------------------------------------------------------------*/
/* Configure GPIO                                                             */
/*----------------------------------------------------------------------------*/
/** Configure pins as
        * Analog
        * Input
        * Output
        * EVENT_OUT
        * EXTI
*/
void MX_GPIO_Init(void)
{

  GPIO_InitTypeDef GPIO_InitStruct = {0};

  /* GPIO Ports Clock Enable */
  __HAL_RCC_GPIOA_CLK_ENABLE();
  __HAL_RCC_GPIOB_CLK_ENABLE();

  /*Configure GPIO pin Output Level */
  HAL_GPIO_WritePin(GPIOB, GPIO_PIN_4|LD2_Pin, GPIO_PIN_RESET);

  /*Configure GPIO pins : PA1 PA4 PA6 PA8
                           PA9 PA12 */
  GPIO_InitStruct.Pin = GPIO_PIN_1|GPIO_PIN_4|GPIO_PIN_6|GPIO_PIN_8
                          |GPIO_PIN_9|GPIO_PIN_12;
  GPIO_InitStruct.Mode = GPIO_MODE_IT_RISING;
  GPIO_InitStruct.Pull = GPIO_NOPULL;
  HAL_GPIO_Init(GPIOA, &GPIO_InitStruct);

  /*Configure GPIO pins : PB4 LD2_Pin */
  GPIO_InitStruct.Pin = GPIO_PIN_4|LD2_Pin;
  GPIO_InitStruct.Mode = GPIO_MODE_OUTPUT_PP;
  GPIO_InitStruct.Pull = GPIO_NOPULL;
  GPIO_InitStruct.Speed = GPIO_SPEED_FREQ_LOW;
  HAL_GPIO_Init(GPIOB, &GPIO_InitStruct);

  /*Configure GPIO pin : PB5 */
  GPIO_InitStruct.Pin = GPIO_PIN_5;
  GPIO_InitStruct.Mode = GPIO_MODE_IT_RISING;
  GPIO_InitStruct.Pull = GPIO_NOPULL;
  HAL_GPIO_Init(GPIOB, &GPIO_InitStruct);

  /* EXTI interrupt init*/
  HAL_NVIC_SetPriority(EXTI1_IRQn, 0, 0);
  HAL_NVIC_EnableIRQ(EXTI1_IRQn);

  HAL_NVIC_SetPriority(EXTI4_IRQn, 0, 0);
  HAL_NVIC_EnableIRQ(EXTI4_IRQn);

  HAL_NVIC_SetPriority(EXTI9_5_IRQn, 0, 0);
  HAL_NVIC_EnableIRQ(EXTI9_5_IRQn);

  HAL_NVIC_SetPriority(EXTI15_10_IRQn, 0, 0);
  HAL_NVIC_EnableIRQ(EXTI15_10_IRQn);

}



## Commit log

2024-11-06 Update Files / Adding Arduino Code for Nucleo board for rate testing
    [Coincidence_board.kicad_pcb, Coincidence_board.kicad_sch]
2024-11-06 Update Coincidence Board / Dephi 2024
    [Coincidence_board-B_Cu.gbr, Coincidence_board-B_Mask.gbr, Coincidence_board-B_Paste.gbr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]
2024-11-07 Update Schematics of Electronic Board
    [Coincidence_board-B_Cu.gbr, Coincidence_board-B_Mask.gbr, Coincidence_board-B_Paste.gbr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]
2024-11-07 Update Test on Nucleo Board - up to 80kHz !!
2024-11-08 Update Schematic
    [Coincidence_board-B_Cu.gbr, Coincidence_board-B_Mask.gbr, Coincidence_board-B_Paste.gbr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]
2025-03-06 Update Coincidence Board / New schematics (Anouk - Jeanne)
    Test with Nucleo L476RG ? Not fast enough ??
    [Coincidence_board-B_Cu.gbr, Coincidence_board-B_Mask.gbr, Coincidence_board-B_Paste.gbr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]
2025-03-06 Update Coincidence Board / 2025 version
    [Coincidence_board-B_Cu.gbr, Coincidence_board-B_Mask.gbr, Coincidence_board-B_Paste.gbr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]
2025-03-07 Create CubeIDE project for STM32 Nucleo board / G431KB
2025-03-08 Update MXIDE code / Adding USART2 transmission of characters / Tested on G431KB and TeraTerm
    [Coincidence_board-B_Cu.gbr, Coincidence_board-B_Mask.gbr, Coincidence_board-B_Paste.gbr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]
2025-03-08 Update Embedded program / STM32CubeIDE / HAL version with 7 EXTI !
    Need to test on 7 inputs / Max frequency ?
2025-03-10 Update Quantum
    [Coincidence_board.kicad_pcb, Coincidence_board.kicad_sch]
2025-03-10 Update Coincidence Board / v2
    [Coincidence_board.kicad_pcb, Coincidence_board.kicad_sch]
2025-03-10 Update GRA experiment / Creating new electronic interface based on G431KB Nucleo board
    [Coincidence_board-B_Cu.gbr, Coincidence_board-B_Mask.gbr, Coincidence_board-B_Paste.gbr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]
2025-03-12 Update Board v2 / Before sending to JLCPCB
    [Coincidence_board-B_Cu.gbr, Coincidence_board-B_Mask.gbr, Coincidence_board-B_Paste.gbr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]
2025-03-29 Update FIR Filter on G431KB / FIR code in STM32CubeIde and MX

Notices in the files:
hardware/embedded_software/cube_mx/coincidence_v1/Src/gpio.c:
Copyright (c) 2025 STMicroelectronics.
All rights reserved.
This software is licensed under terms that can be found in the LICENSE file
